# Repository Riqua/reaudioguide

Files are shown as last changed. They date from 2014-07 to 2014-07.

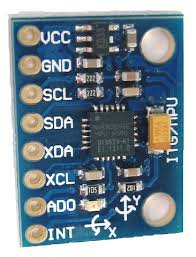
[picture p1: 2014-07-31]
Arduino/MPU6050-breakout.jpg

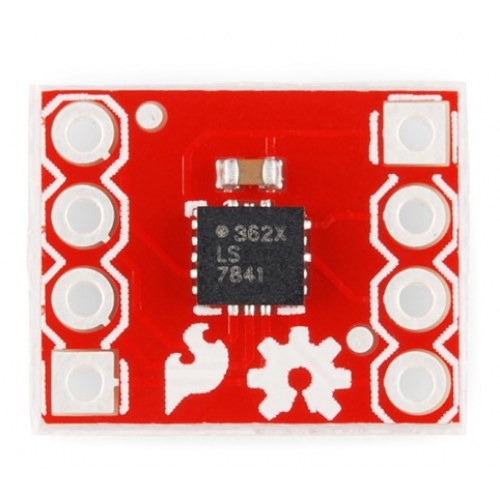
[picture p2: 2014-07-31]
Arduino/ADXL362-breakout.jpg

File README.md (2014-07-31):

reaudioguide
============

Project for the recycling and recovery of obsolete mp3 players. Mp3 players thus recovered are enhanced with an inclinometer controlled by Arduino, and act as audio-guides for blind users in small museums. GUI made with a 3d model made by milling / 3d printing, which controls a smartphone or a PC

Here's how it works the prototype https://www.youtube.com/watch?v=hEOTnotyFFc

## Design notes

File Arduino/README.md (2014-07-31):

This folder collect PCB files (PNG, SVG, Fritzing), Arduino's sketches and libraries.

In addition there will be codes and layouts made with different types of boards and sensors. At this stage, we used two boards (Arduino UNO and ReadBear BLE Micro) and two sensor breakouts (ADXL362 and MPU6050). The breakouts are depicted in JPEG files in this folder.

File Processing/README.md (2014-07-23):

Download the demo track to http://cult.riqua.eu/demoreaudioguide

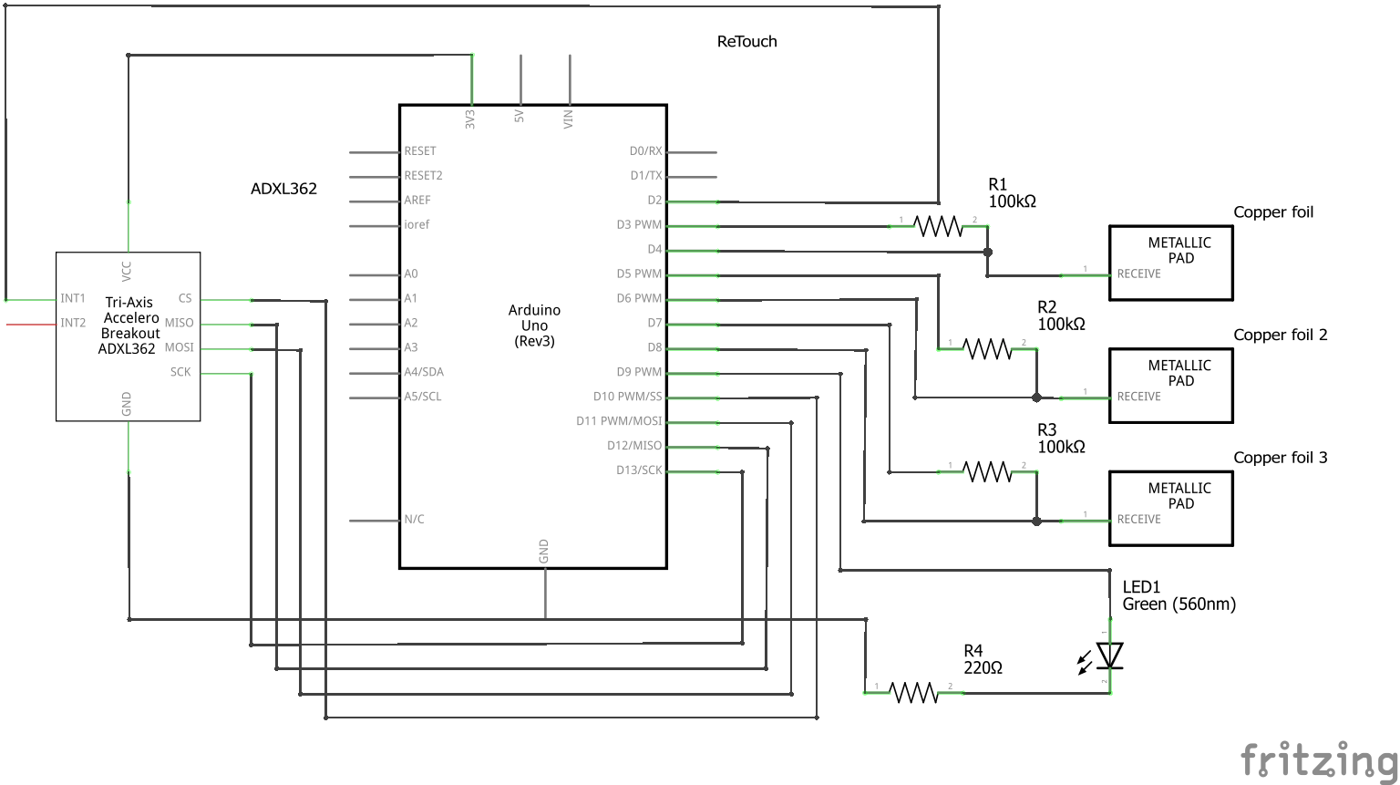
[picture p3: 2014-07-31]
Arduino/UNO-ADXL362/PCB/ReTouch_UNO-ADXL362_schem.png

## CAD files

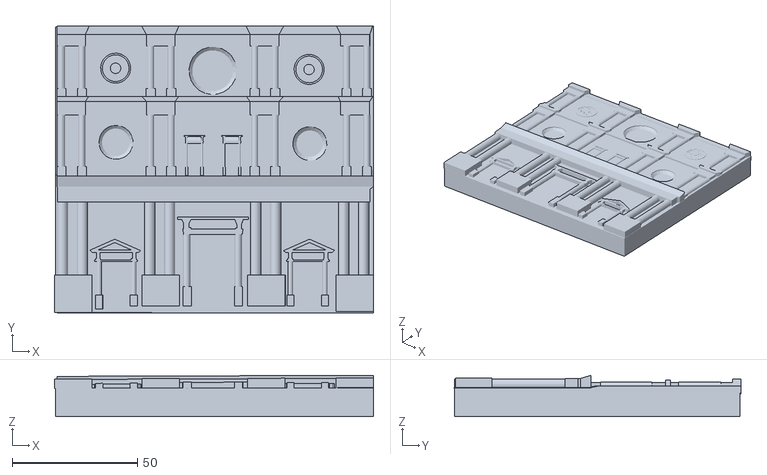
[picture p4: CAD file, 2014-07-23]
Example/San_Bernardino/model-draft.stl
127.4 x 114.4 x 16.5

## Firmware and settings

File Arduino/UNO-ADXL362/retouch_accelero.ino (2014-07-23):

/*
Connect SCLK, MISO, MOSI, and CSB of ADXL362 to
SCLK, MISO, MOSI, and DP 10 of Arduino 
(check http://arduino.cc/en/Reference/SPI for details)
 
*/ 
#include <LowPower.h>
#include <SPI.h>
#include <ADXL362.h>
#include <CapacitiveSensor.h>

ADXL362 xl;

int16_t interruptPin = 2;          //Setup ADXL362 interrupt output to Interrupt 0 (digital pin 2)
int16_t interruptStatus = 0;

int16_t temp;
int16_t XValue, YValue, ZValue, Temperature;

CapacitiveSensor capSensor = CapacitiveSensor(7,6);
CapacitiveSensor capSensor2 = CapacitiveSensor(9,8);
CapacitiveSensor capSensor3 = CapacitiveSensor(5,4);
int threshold = 360; 

int statoplay= 8;
int stato= 0;
int traccia = 0;

void setup(){
  
  Serial.begin(800);
  xl.begin(10);                   // Setup SPI protocol, issue device soft reset
 
  delay(1000);    
    // Setup digital pin 7 for LED observation of awake/asleep  
    pinMode(3, OUTPUT);    
    digitalWrite(3, HIGH);
    

    //  Setup Activity and Inactivity thresholds
    //     tweaking these values will effect the "responsiveness" and "delay" of the interrupt function
    //     my settings result in a very rapid, sensitive, on-off switch, with a 2 second delay to sleep when motion stops
    xl.setupDCActivityInterrupt(200, 10);		// 300 code activity threshold.  With default ODR = 100Hz, time threshold of 10 results in 0.1 second time threshold
    xl.setupDCInactivityInterrupt(80, 1000);		// 80 code inactivity threshold.  With default ODR = 100Hz, time threshold of 30 results in 100 second time threshold
    
    // Setup ADXL362 for proper autosleep mode
    //
	
    // Map Awake status to Interrupt 1
    // *** create a function to map interrupts... coming soon
    xl.SPIwriteOneRegister(0x2A, 0x40);   
	
    // Setup Activity/Inactivity register
    xl.SPIwriteOneRegister(0x27, 0x3F); // Referenced Activity, Referenced Inactivity, Loop Mode  
        
    // turn on Autosleep bit
    byte POWER_CTL_reg = xl.SPIreadOneRegister(0x2D);
    POWER_CTL_reg = POWER_CTL_reg | (0x04);				// turn on POWER_CTL[2] - Autosleep bit
    xl.SPIwriteOneRegister(0x2D, POWER_CTL_reg);

    //
    // turn on Measure mode
    //
    xl.beginMeasure();                      // DO LAST! enable measurement mode   
    xl.checkAllControlRegs();               // check some setup conditions    
    delay(100);
    // Setup interrupt function on Arduino
    //    IMPORTANT - Do this last in the setup, after you have fully configured ADXL.  
    //    You don't want the Arduino to go to sleep before you're done with setup
    //
    pinMode(2, INPUT);    
    attachInterrupt(0, interruptFunction, RISING);  // A high on output of ADXL interrupt means ADXL is awake, and wake up Arduino 

}

void loop(){
  //
  //  Check ADXL362 interrupt status to determine if it's asleep
  //
  interruptStatus = digitalRead(interruptPin);

// if ADXL362 is asleep, call LowPower.powerdown  
  if(interruptStatus == 0) { 
    digitalWrite(3, LOW);    // Turn off LED as visual indicator of asleep
    delay(100);
    LowPower.powerDown(SLEEP_FOREVER, ADC_OFF, BOD_OFF);     
  }
  
// if ADXL362 is awake, report XYZT data to Serial Monitor
  else{
    delay(10);
    digitalWrite(3, HIGH);    // Turn on LED as visual indicator of awake
    xl.readXYZTData(XValue, YValue, ZValue, Temperature);  	     
  }
  // give circuit time to settle after wakeup
  delay(20);

  long sensorValue = capSensor.capacitiveSensor(3);
  long sensorValue2 = capSensor2.capacitiveSensor(3);
  long sensorValue3 = capSensor3.capacitiveSensor(3);
  
   if(sensorValue2 > threshold){
     if(traccia != 2){
       Serial.write(2); //Play the second track: Ordine basso della facciata,
       traccia = 2;
     }
  }
   if(sensorValue3 > threshold){
     if(traccia != 3){
       Serial.write(3); //Play the second track: Ordine basso della facciata,
       traccia = 3;
     }
  }
  if(sensorValue > threshold) {
    if(traccia != 1){
     Serial.write(1); //Play the first track: Piazza,
     traccia = 1;
    }
  }
  xl.readXYZTData(XValue, YValue, ZValue, Temperature);  
  
  if(XValue > 1100 || XValue < -1100) {
    if(statoplay != 8){
      Serial.write(8); //Pause mode,
      statoplay = 8;
      traccia = 0;
    }
  }else{
     if((statoplay != 9)&&(XValue < 600 && XValue > -600)){
       Serial.write(9); //Play mode,
       statoplay=9; //
       traccia = 0;
     } 
  }
  if(YValue > 500) {
    if(YValue > 1200) {
      if(stato != 12){
         Serial.write(12); //Rewind the track,
         stato=12;
      }
    }else{
      if(stato == 12){
        if(YValue < 700) {
          Serial.write(13); //return in play mode after rewind,
          stato=0;
        }
      }
    }
  }
  if(YValue < -500) {
    if(YValue < -1200) {
      if(stato != 22){
         Serial.write(22); //Foward the track,
         stato=22;
      }
    }else{
      if(stato == 22){
        if(YValue > -700) {
          Serial.write(23); //return in play mode after foward,
          stato=0;
        }
      }
    }
  }
/* Serial.println(Temperature);	 */ 
  delay(20);        
}

//
// Function called if Arduino detects interrupt activity
//    when rising edge detected on Arduino interrupt
//
void interruptFunction(){
  Serial.write(0);
}

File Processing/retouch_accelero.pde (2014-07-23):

import processing.serial.*;
import ddf.minim.*;
import ddf.minim.analysis.*;

Minim minim;
AudioPlayer audiotrack;
AudioMetaData meta;
int songLength=0;

boolean cell_1 = false;
Serial myPort;
int autorizz;
int indexForNames = 0;
int nowPlaying;
int pausePlaying;
int countRewind;
int countFoward;
int countRewFow;

void setup() {
  size(512, 512);
  //smooth();
  //noStroke();
  //ellipseMode(CENTER);
  nowPlaying = 0;
  autorizz = 9;
  countRewFow=0;
  pausePlaying = -1000; //milliseconds that must pass after a pause input, before it can be made again a play
  myPort = new Serial(this, Serial.list()[Serial.list().length-1], 800);
  minim = new Minim(this);
  audiotrack = minim.loadFile("track"+indexForNames+".mp3");
}
void draw() {
  int lettura = myPort.read();
  if (lettura == 8 || lettura == 22 || lettura == 12) {
    autorizz = 8;
  }else{
    autorizz = 9;
  }

  if (autorizz == 9 && (millis() - pausePlaying) > 1000){
    if (lettura >= 0 || lettura <= 4) {
// 1, 2, 3 and 4 are the signals to play the four specific audio-tracks
// 0 is general audio-track. The general track is activated the first time that the audioguide comes out of standby mode.
      if(!(lettura == 0 && audiotrack.isPlaying())){ //a NAND operation to prevent the play of general audio-track while a user is listening to another track
        if(nowPlaying !=lettura){ // if a user touches the sensor relative to the current track, the track is not charged again
          indexForNames = lettura;
          audiotrack.pause();
          audiotrack = minim.loadFile("track"+indexForNames+".mp3");
          songLength=audiotrack.length();
          meta = audiotrack.getMetaData();
        }
        audiotrack.play();
        nowPlaying = lettura;
      }
    }
  }

 if (lettura == 8){ // 8 is the STOP signal: Arduino sends 8, via serial, when the model is tilted downward
  if (audiotrack.isPlaying()) {audiotrack.pause();}
  pausePlaying = millis(); // is saved the moment of pause. We want, after pausing, it is impossible to start with a new play before the lapse of time (1 second)
 }

  //if (lettura == 12 && audiotrack.isPlaying() || countRewFow != 0){
  if (lettura == 12 && audiotrack.isPlaying() || countRewind != 0){
//12 and 22 are respectively the signals for REWIND and FOWARD. Arduino sends 12 or 22 when the model is tilted (respectively) to the left or right
    if (audiotrack.isPlaying()) {audiotrack.pause();}
    countRewind = countRewind - 180;
 }
  if (lettura == 22 && audiotrack.isPlaying() || countFoward != 0){
//12 and 22 are respectively the signals for REWIND and FOWARD. Arduino sends 12 or 22 when the model is tilted (respectively) to the left or right
    if (audiotrack.isPlaying()) {audiotrack.pause();}
    countFoward = countFoward + 180;
 }
 if (lettura == 13 || lettura == 23){
    countRewFow = countRewind + countFoward;
    audiotrack.skip(countRewFow);
    countRewind=0;
    countFoward=0;
    audiotrack.play();
 }




  background(5);
if ( audiotrack.isPlaying())
  {text("The audiotrack is playing.", 5, 15);
    //if (!(meta==null))
    //  buttonProgressData.w = map(song.position(), 0, meta.length(), 0, width-24 );
    //buttonProgressData.display();
  showMeta() ;
}
  else
  {text("The audiotrack is not playing.", 5, 35);}

  delay(30);
  
  
  
}

void stop()
{
  audiotrack.close();
  minim.stop();
  super.stop();
}

void showMeta() {
  // 
  // data for meta information
  int ys = 115;  // y start-pos
  int yi = 16;   // y line difference
  //
  int y = ys;
  fill(255);
  if (!(meta==null)) {
    //textTab("File Name: \t" + showSongWithoutFolder(), 5, y);
    textTab("Length: \t" + strFromMillis(meta.length()), 5, y+=yi);
    textTab("Title: \t" + meta.title(), 5, y+=yi);
    textTab("Author: \t" + meta.author(), 5, y+=yi);
    textTab("Album: \t" + meta.album(), 5, y+=yi);
    textTab("Date: \t" + meta.date(), 5, y+=yi);
    textTab("Comment: \t" + meta.comment(), 5, y+=yi);
  } // if
}

void textTab (String s, float x, float y)
{
  // makes \t as tab for a table for one line
  // only for 2 columns yet
  // indent:  
  int indent = 90;
  //
  s=trim ( s );
  String [] texts = split (s, "\t");
  s=null;
  texts[0]=trim(texts[0]);
  text (texts[0], x, y);
  //
  // do we have a second part?
  if (texts.length>1&&texts[1]!=null) {
    // is the indent too small
    if (textWidth(texts[0]) > indent) {
      indent = int (textWidth(texts[0]) + 10);
    } // if
    //
    texts[1]=trim(texts[1]);
    text (texts[1], x+indent, y);
  }
} // func

String strFromMillis ( int m ) {
  // returns a string that represents a given millis m as hrs:minute:seconds
  float sec;
  int min;
  //
  sec = m / 1000;
  min = floor(sec / 60); 
  sec = floor(sec % 60);
  // over one hour?
  if (min>59) {
    int hrs = floor(min / 60);
    min = floor (min % 60);
    return  hrs+":"+nf(min, 2)+":"+nf(int(sec), 2);
  }
  else
  {
    return min+":"+nf(int(sec), 2);
  }
}

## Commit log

2014-07-15 From prototype 2 beta: processing
    - Rationalization of the functions and the loops
    - Implementation of rewind function
2014-07-15 From prototype 2 beta: processing
    - Remove useless comments
    - sincro serial speed with processing
2014-07-23 Sleep version
    - Sleep (low power) function for accelerometer
    - Include libraries
    - Include a draft of .stl file
    [model-draft.stl]
2014-07-31 Update sensors & repath arduino folders
    - Arduino folders now are divided depending on the hardware used.
    - Added MPU6050 sensor library
    - Added hardware scheme for UNO+ADXL362
    [ReTouch_UNO-ADXL362.fzz]
2014-07-31 Draft video-tutorial
    - Insertion of link to draft videotutorial
